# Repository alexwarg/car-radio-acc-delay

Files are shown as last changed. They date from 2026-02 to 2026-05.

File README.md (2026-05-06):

# Car Head-Unit ACC Timer

A small circuit and firmware based on an ATtiny85 that adds independent power-button control to a car head unit.

The device sits in-line with the vehicle's ACC (accessory/ignition) signal and gives you two extra capabilities:

- **ACC on:** the button can toggle the head unit off or back on while the ignition remains on.
- **ACC off:** the button turns the head unit on with an automatic 30-minute power-off timer, so you can keep listening after parking without draining the battery.

Power consumption in the off state is around 40 µA.

The project is available under the MIT license (see `LICENSE.txt`).

## Hardware

Minimal component count around an ATtiny85, designed for very low quiescent current.

The KiCad schematic and PCB layout are in `hardware/auto-acc-timer/`. A 3D-printable housing is in `hardware/auto-acc-timer/housing/`.

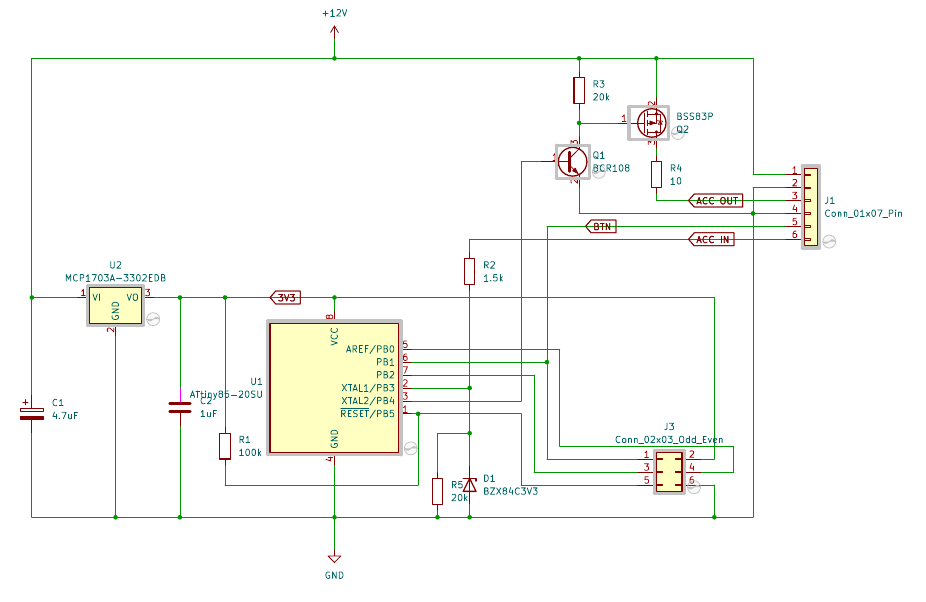
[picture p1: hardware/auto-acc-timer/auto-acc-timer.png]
Schematic


### MCU Pin Assignment

| Pin | Direction | Signal |
|-----|---|---|
| PB1 | Input | Power button (active low, internal pull-up) |
| PB3 | Input | ACC input from vehicle |
| PB4 | Output | ACC output to head unit |
| PB0 | I²C SDA | Optional OLED display |
| PB2 | I²C SCL | Optional OLED display |

### J1 — Main Connector (1×6, 2.54 mm)

| Pin | Signal | Description |
|-----|---|---|
| 1 | +12V | Vehicle power input |
| 2 | GND | Ground |
| 3 | ACC OUT | Switched ACC output to head unit |
| 4 | GND | Ground |
| 5 | BTN | Power button input |
| 6 | ACC IN | ACC input from vehicle ignition |

### J3 — ISP Programming Header / OLED Display (2×3, 2.54 mm)

| Pin | Signal | Description |
|-----|---|---|
| 1 | MOSI (PB1) | SPI data in — shared with BTN net |
| 2 | VCC (3V3) | 3.3 V supply |
| 3 | SCK (PB2) | SPI clock / I²C SCL |
| 4 | MISO (PB0) | SPI data out / I²C SDA |
| 5 | RESET | MCU reset |
| 6 | GND | Ground |

J3 doubles as the OLED display connector. Connect an SSD1306 128×32 display using pins 2 (VCC), 3 (SCL), 4 (SDA), and 6 (GND).

## Operating Modes

| Condition | Short press | Long press |
|---|---|---|
| ACC on, output on | Turn output off | — |
| ACC on, output off | Turn output on | — |
| ACC off, output off | Turn output on (starts 30 min timer) | — |
| ACC off, timer running | Cancel timer, turn output off | Reset timer to 30 min |

When the timer expires the output is cut automatically.

## Optional OLED Display

Compile with `USE_I2C=1` to enable an SSD1306 OLED (128×32) that shows the remaining time in `MM:SS` using a 7-segment font. A settings menu (long-press when idle) lets you adjust the power-off timer and the ACC-off delay; values are stored in EEPROM.

## Building

Requires `avr-g++` (C++20) and `avrdude`. The programmer is a Bus Pirate on `/dev/ttyUSB0`.

```sh
# Build firmware
make

# Flash firmware and EEPROM
make upload

# Regenerate font headers (requires tools/ttf2bmh.py)
make fonts
```

The build output lands in `.build/src/firmware.hex`.

## Software Overview

| File | Purpose |
|---|---|
| `src/main.cc` | Application logic, pin setup, task loop |
| `src/timer.h` | 40-bit timer on USI/Timer1, ~1 kHz resolution at 8 MHz |
| `src/debounce.h` / `btn.h` | Debounce and button event detection (short/long/double press) |
| `src/task_list.h` | Cooperative task scheduler with idle-mode sleep |
| `src/i2c.h` | Non-blocking bit-bang I²C master driven by a flash-resident command program |
| `src/display.h` / `display.cc` | SSD1306 driver and font renderer |

See [`doc/i2c.md`](doc/i2c.md) for a detailed description of the I²C implementation.

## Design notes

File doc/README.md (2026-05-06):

This is firmware for an AVR microcontroller (likely ATtiny85 or similar) that implements an ACC (accessory power) delay timer for 
a car radio. Here's what the code does:

## Core Purpose

It sits between a car's ACC ignition signal and the car radio, giving you manual control over when the radio turns off — useful
for listening to the radio after parking without draining the battery.

## How It Works

### Inputs:

 - ACC_IN (pin 3): The car's ignition/ACC signal
 - PWR_BTN (pin 1): A manual power button

### Output:

 - ACC_OUT (pin 4): The signal sent to the radio

### Operating Modes (Timed_pwr_on)

1. ACC on (P_acc): When the ignition is on, the radio output mirrors it. The button can toggle the radio off/on while ignition
remains on.
2. Timer mode (P_timer): When the ignition turns off, you can press the button to keep the radio on for a 30-minute countdown. A
long press resets the timer back to 30 minutes. When the timer expires, it cuts power automatically
3. Off (P_off): Radio output is off.

## Supporting Components

 - timer.h: A 40-bit hardware timer built on AVR Timer1 with an 8192 prescaler, providing ~1kHz resolution at 8MHz. Used for
   debouncing and timeout tracking.
 - debounce.h / btn.h: Debounce logic for the ACC input and button, distinguishing short press, long press, and double-click.
 - task_list.h: A cooperative task loop that puts the MCU to sleep (idle mode) between events to save power, waking on pin-change  
   interrupts.
 - display.h / i2c.h: Optional SSD1306 OLED display support (compiled with USE_I2C=1) to show remaining time in MM:SS format using 
   a 7-segment font, plus a settings menu for configuring the timers — stored in EEPROM.
 - display.cc: Font rendering logic for blitting characters to the OLED over I2C.

## Summary

Short press while ACC is off → turn radio on with 30-min timer. Long press while timer is ticking → reset timer to 30 min. Timer
expires → radio off. With the display enabled, you also get a settings UI to configure the timeout duration via EEPROM.

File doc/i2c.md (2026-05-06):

# I2C Implementation

The I2C implementation is a **software bit-bang master** using the AVR's USI (Universal Serial Interface) peripheral as a shift register.

## Physical Layer

The USI hardware on the ATtiny handles the actual bit shifting. `USICR` configures it in two-wire mode with external clock, and `USIDR` holds the data register. The `_usitc()` call toggles SCL via the USI control register, which also clocks the shift register. SDA is manipulated directly as a GPIO.

Start and stop conditions are generated manually by controlling SDA/SCL timing: start = SDA goes low while SCL is high; stop = SDA goes high while SCL is high.

## Command Queue

Rather than a blocking loop, the driver is **non-blocking and cooperative**. All I2C operations are described as a compile-time byte sequence of commands stored in flash (program memory via `Pgm`). The command opcodes are:

| Opcode | Meaning |
|---|---|
| `C_start` | Generate I2C start condition |
| `C_stop` | Generate I2C stop condition |
| `C_send_bytes_inline` | Send N bytes embedded in the command stream |
| `C_send_bytes` | Send N bytes from a pointer |
| `C_send_bytes_rep` | Repeat a single byte N times (for clearing display RAM) |
| `C_send_bytes_rep_len` | Same but length comes from a RAM struct at runtime |
| `C_send_bytes_ram_len` | Send N bytes from a RAM pointer (for dynamic data) |
| `C_callback` | Call a function mid-sequence without stopping |
| `C_end` | End of sequence, call finalizer |

`_next_cmd()` walks this byte stream, dispatching each opcode. The `resume` function pointer holds where to continue next time `step()` is called from the main task loop.

## Byte Transmission

`_send_byte<get_dr>()` loads `USIDR` with the next byte, then `_send_bits_loop()` clocks it out 8 times using `_usitc()`. After 8 bits (`USISR & USIOIF`), it switches SDA to input to receive the ACK/NACK from the device. If NACK, it aborts and calls `_stop()`; if ACK and more bytes remain, it recurses; otherwise advances to `_next_cmd()`.

## Do-While Loop Construct

`do_while_end<condition, finish>(code)` is a compile-time helper that builds a command sequence with a tail callback that re-jumps to the start of the sequence if `condition()` returns true. This is how `Display::time()` iterates over 5 digit positions — the loop state is kept in `Disp_time::state` in RAM, and the condition lambda increments `state.pos` each pass.

## Command Construction with `mk_cmds`

`mk_cmds(...)` uses variadic templates and `Packed_tuple` to concatenate heterogeneous command structs into a single tightly-packed byte array at compile time, which then gets placed in flash via `Pgm(...)`. The result is zero runtime overhead for building the command sequences — they're fully laid out at compile time.

## Summary

A non-blocking I2C master where the entire operation (init OLED, clear, draw digits, loop) is described as a flash-resident command program, executed one step per main-loop tick, with a function pointer as the "program counter". Very tight for an 8-bit MCU with 512 bytes of RAM.

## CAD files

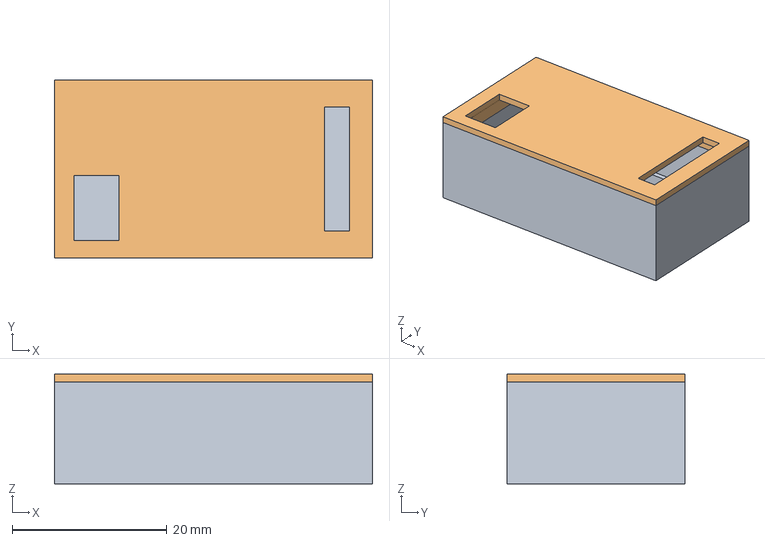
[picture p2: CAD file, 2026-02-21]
hardware/auto-acc-timer/housing/housing.FCStd
41.1 x 23.0 x 14.2 mm

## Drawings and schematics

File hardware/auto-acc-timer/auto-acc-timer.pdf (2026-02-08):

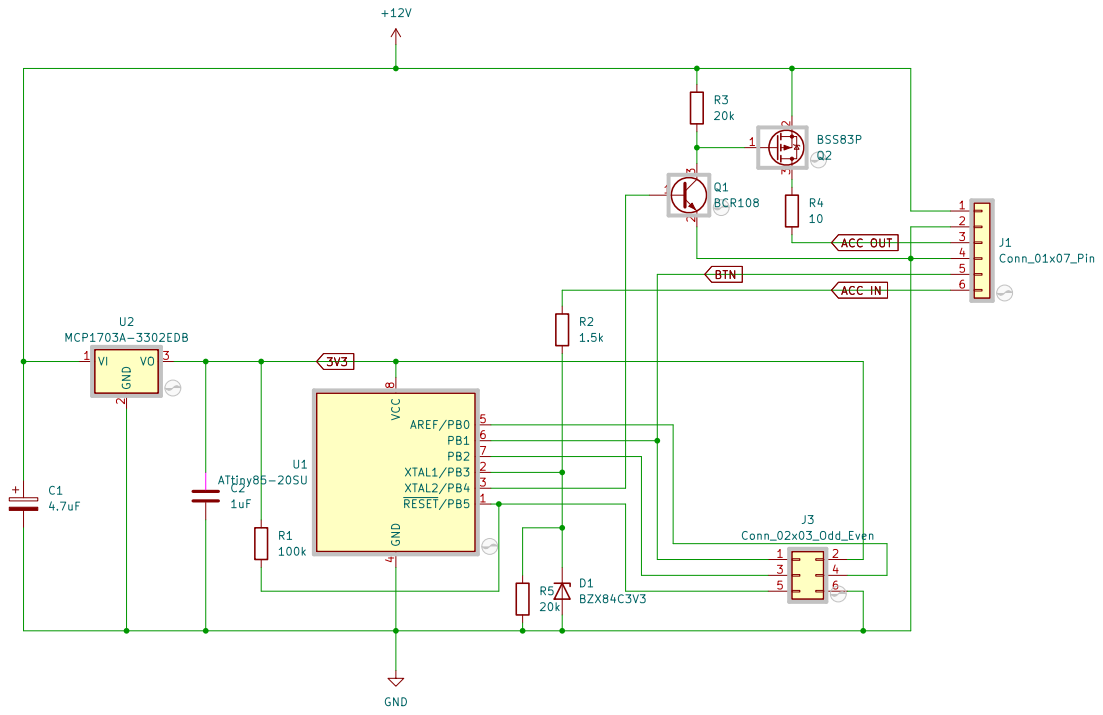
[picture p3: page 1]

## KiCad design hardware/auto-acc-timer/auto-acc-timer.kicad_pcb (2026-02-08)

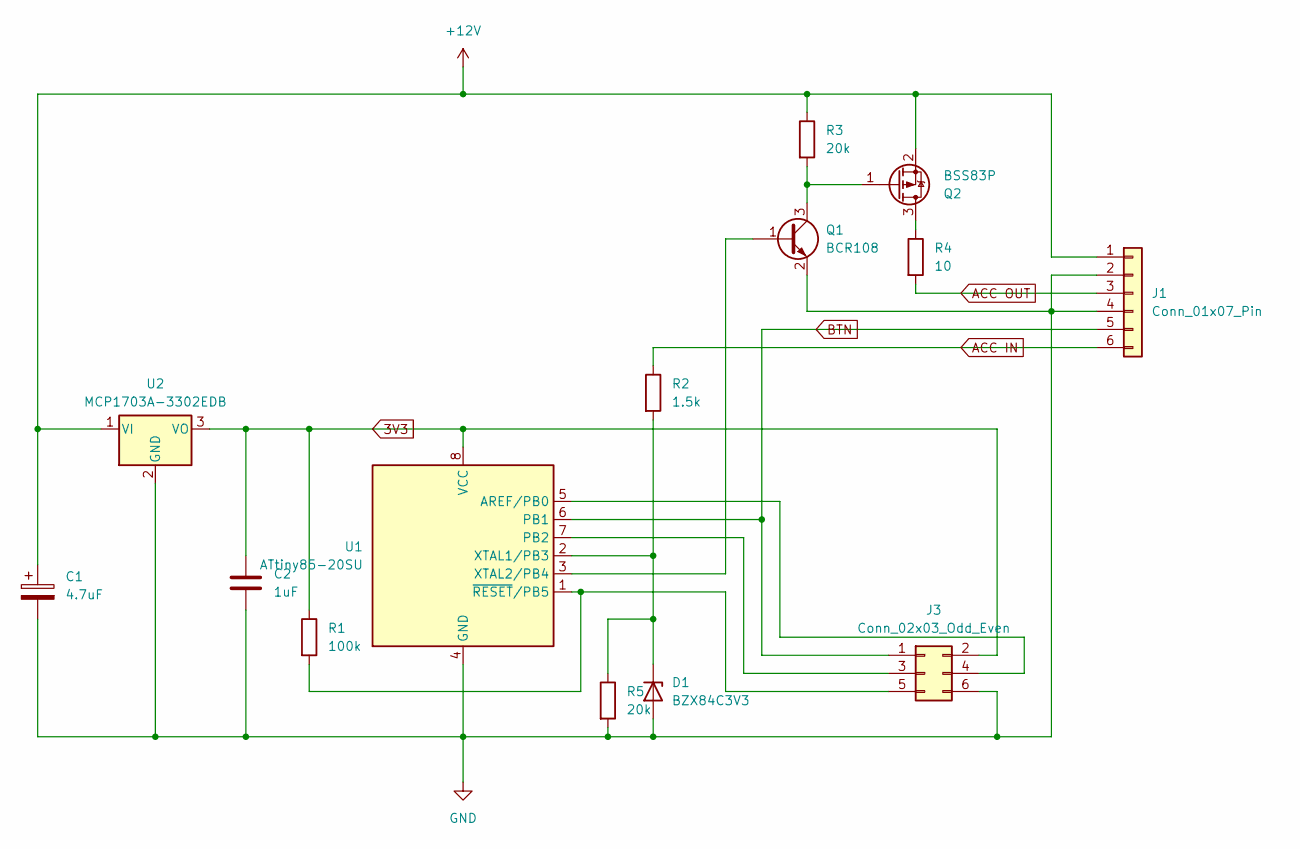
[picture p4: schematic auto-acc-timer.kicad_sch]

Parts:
C1: 4.7uF; CP_Elec_4x5.8
C2: 1uF; C_0805_2012Metric_Pad1.18x1.45mm_HandSolder
D1: BZX84C3V3; SOT-23
J1: Conn_01x07_Pin; PinHeader_1x06_P2.54mm_Vertical
J3: Conn_02x03_Odd_Even; PinHeader_2x03_P2.54mm_Vertical
Q1: BCR108; SOT-23
Q2: BSS83P; SOT-23
R1: 100k; R_0805_2012Metric_Pad1.20x1.40mm_HandSolder
R2: 1.5k; R_0805_2012Metric_Pad1.20x1.40mm_HandSolder
R3, R5: 20k; R_0805_2012Metric_Pad1.20x1.40mm_HandSolder
R4: 10; R_0805_2012Metric_Pad1.20x1.40mm_HandSolder
U1: ATtiny85-20SU; SOIC-8_5.3x5.3mm_P1.27mm
U2: MCP1703A-3302EDB; SOT-223-3_TabPin2

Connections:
3V3: C2.1, J3.2, R1.1, U1.8 (VCC), U2.3 (VO)
+12V: C1.1, J1.1, Q2.2 (S), R3.1, U2.1 (VI)
ACC IN: J1.6, R2.1
ACC OUT: J1.3, R4.2
BTN: J1.5, J3.1, U1.6 (PB1)
GND: C1.2, C2.2, D1.1 (A), J1.2, J1.4, J3.6, Q1.2 (E), R5.2, U1.4 (GND), U2.2 (GND)
unnamed: D1.3 (K), R2.2, R5.1, U1.2 (XTAL1/PB3)
unnamed: J3.3, U1.7 (PB2)
unnamed: J3.4, U1.5 (AREF/PB0)
unnamed: J3.5, R1.2, U1.1 (~RESET/PB5)
unnamed: Q1.1 (B), U1.3 (XTAL2/PB4)
unnamed: Q1.3 (C), Q2.1 (G), R3.2
unnamed: Q2.3 (D), R4.1

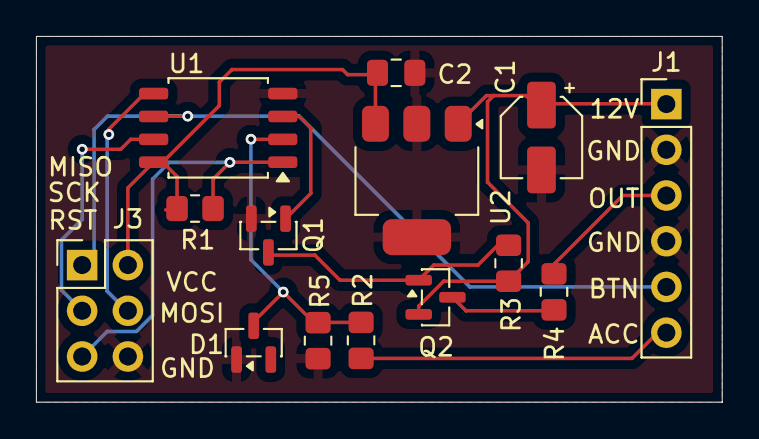
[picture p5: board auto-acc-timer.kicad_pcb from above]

Board: 2 copper layers, 38.1 x 20.3 mm, 14 parts (0 on the bottom side), 13 nets.

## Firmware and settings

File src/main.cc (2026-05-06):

// Licensed under the MIT License. See LICENSE.txt file in the project root.

/**
 * ACC timer
 *
 * The project is designed to take two inputs, an ingition (ACC) signal, and a power button.
 * The output is an ignition (ACC) signal with extra function:
 *  - In case the ACC input transitions from low-to-high the ACC output is switched to high.
 *    As long ass ACC input remains high, the button allows switch off and on of the ACC output.
 *  - In case of ACC input is low, the button allows to toggle the ACC output on and off, with
 *    an additional timer of 30 minutes to automatically switch off the ACC output.
 */

#include <cstddef>

#include <avr/io.h>
#include <avr/interrupt.h>
#include <avr/pgmspace.h>
#include <avr/eeprom.h>

#include "timer.h"
#include "irq_guard.h"
#include "debounce.h"
#include "btn.h"
#include "cxx_duration.h"
#include "task_list.h"
#include "sleep_support.h"

#include "i2c.h"
#include "display.h"


enum {
  ACC_OUT_PIN = 4,
  ACC_IN_PIN  = 3,
  PWR_BTN_PIN = 1,

  ACC_OUT_MSK = 1 << ACC_OUT_PIN,
  ACC_IN_MSK  = 1 << ACC_IN_PIN,
  PWR_BTN_MSK = 1 << PWR_BTN_PIN,
};

enum : unsigned long
{
  PWR_DOWN_DELAY_SEC = 30 * 60ul, // poer off timer for manually powerd on mode (without ACC on)
  ACC_DOWN_DELAY_SEC = 0, // delay power down after ACC off for n seconds
};

#define USE_I2C 0

template<typename T>
class Eem
{
  T _v;

public:
  Eem() = default;
  constexpr Eem(T const &v) noexcept : _v(v) {}
  Eem(Eem const &) = delete;
  Eem(Eem &&) = delete;
  Eem &operator = (Eem const &) = delete;
  Eem &operator = (Eem &&) = delete;


  T get() const noexcept { return T(eeprom_read_word(&_v._c)); }
  void write(T const &v) noexcept { eeprom_write_word(&_v._c, v.count()); }

  operator T () const noexcept { return get(); }


};

//---------------------------------------------------------
//  main application logic: handling the ACC output pin
//  accoring to input state and timer based power-off...
template<unsigned long ON_TIME_SECS>
struct Timed_pwr_on
{
  using Cnt_max_type = cxx::qseconds<~0ul>;
  static constexpr cxx::seconds On_time = ON_TIME_SECS;
  static constexpr cxx::milliseconds On_time_ms = On_time;
  static constexpr Cnt_max_type On_time_qs = cxx::duration_cast<Cnt_max_type>(On_time);
  using Cnt_type = cxx::qseconds<2 * On_time_qs.count()>;

  static constexpr cxx::seconds Acc_delay = ACC_DOWN_DELAY_SEC;
  static constexpr Cnt_max_type Acc_delay_qs = cxx::duration_cast<Cnt_max_type>(Acc_delay);

#if USE_I2C
  static Eem<Cnt_type> On_time_diff;
  static Eem<Cnt_type> Acc_delay_diff;
#else
  static constexpr Cnt_type On_time_diff = On_time_qs;
  static constexpr Cnt_type Acc_delay_diff = Acc_delay_qs;
#endif

  enum
  {
    P_off   = 0, //< ACC output is off
    P_acc   = 1, //< ACC output is on due to ACC input on
    P_timer = 2, //< ACC output is on and power-off timer is ticking

    P_settings = 4,
    P_edit_setting = 8,
    P_set_off_tmr = 0x00,
    P_set_acc_delay =0x10,
  };

  Cnt_type _pwr_off_time;
  uint8_t _pwr;

#if USE_I2C
  bool in_settings() const { return _pwr & P_settings; }
  bool in_settings_edit() const { return _pwr & P_edit_setting; }
#else
  bool in_settings() const { return false; }
  bool in_settings_edit() const { return false; }
#endif

  uint8_t current_setting() const
  {
    return _pwr & P_set_acc_delay;
  }

  uint8_t next_setting()
  {
    _pwr ^= P_set_acc_delay;
    return current_setting();
  }

  void enter_settings()
  {
    _pwr = (_pwr & 7) | P_settings;
  }

  void leave_settings()
  {
    _pwr = (_pwr & 3);
  }

  void enter_settings_edit()
  {
    _pwr |= P_edit_setting;
  }

  void leave_settings_edit()
  {
    _pwr &= ~P_edit_setting;
  }

  bool is_on() const
  {
    return _pwr & (P_acc | P_timer);
  }

  bool is_ticking() const
  {
    return _pwr & P_timer;
  }

  Cnt_type eta(Cnt_type now) const
  { return _pwr_off_time - now; }


  bool timeout(Cnt_type now) const
  {
    if (!(_pwr & P_timer))
      return false;

    using Scnt = cxx::signed_type_t<Cnt_type>;

    if (static_cast<Scnt>(now - _pwr_off_time) >= Scnt::zero())
      return true;

    return false;
  }

  void hit()
  {
    _pwr &= ~P_timer;
    switch_acc_off();
  }

  void start_timer(Cnt_type timer)
  {
    _pwr_off_time = timer;
    _pwr |= P_timer;
  }

  bool stop_timer()
  {
    if (!(_pwr & P_timer))
      return false;

    _pwr &= ~P_timer;
    return true;
  }

  bool running() const { return _pwr & P_timer; }
  // timers always can sleep, just might not power down...
  bool might_sleep() const { return true; }
  // timers always can sleep, just might not power down...
  bool might_power_down() const { return !running(); }

  void switch_acc_on()
  {
    PORTB |= ACC_OUT_MSK;
  }

  void switch_acc_off()
  {
    PORTB &= ~ACC_OUT_MSK;
  }

  template<typename ACC>
  bool power_btn(ACC const &acc, Cnt_type now)
  {
    if (_pwr & P_timer)
      {
        stop_timer();
        switch_acc_off();
        return true;
      }

    if (_pwr & P_acc)
      {
        _pwr &= ~P_acc;
        switch_acc_off();
        return true;
      }

    // off
    if (acc.state())
      _pwr |= P_acc;
    else
      start_timer(now + On_time_diff);

    switch_acc_on();
    return false;
  }

  void long_btn_press(Cnt_type now)
  {
    if (is_ticking())
      start_timer(now + On_time_diff);
  }

  template<typename ACC>
  void acc_update(ACC const &acc, Cnt_type now)
  {
    if (acc.state())
      {
        if (_pwr & P_timer)
          _pwr = (_pwr & ~P_timer) | P_acc;
        else if (!(_pwr & P_acc))
          {
            _pwr |= P_acc;
            switch_acc_on();
          }

        return;
      }

    // acc input is off ...
    if (_pwr & P_acc)
      {
        _pwr &= ~P_acc;
        if (!in_settings() && (Cnt_type)Acc_delay_diff)
          start_timer(now + Acc_delay_diff);
        else
          switch_acc_off();
      }
  }

  // task loop API
  using update_time_type = Cnt_type;
  using wakeup_time_type = Cnt_type;

  static void init(auto &&...) {}

  void update(auto const &now, auto &&...)
  {
    // if we hit the timeout, handle it
    if (timeout(cxx::duration_cast<Cnt_type>(now)))
      hit();
  }

  bool wakeup_pending(auto const &now) const
  {
    return timeout(now);
  }

  static void clear_wakeups() {}
};

#if USE_I2C
template<unsigned long ON_TIME_SECS>
EEMEM Eem<typename Timed_pwr_on<ON_TIME_SECS>::Cnt_type> Timed_pwr_on<ON_TIME_SECS>::On_time_diff(On_time_qs);

template<unsigned long ON_TIME_SECS>
EEMEM Eem<typename Timed_pwr_on<ON_TIME_SECS>::Cnt_type> Timed_pwr_on<ON_TIME_SECS>::Acc_delay_diff(Acc_delay_qs);
#endif

//---------------------------------------------------------
// Timer / Clock instance
static cxx::Timer timer;

static void init_clk()
{
  CLKPR = 0x80;
  CLKPR = 0x00; // prescaler: 0 -> 8MHz
}

static void init_timer1()
{
  TCCR1 = 0x0e; // normal mode + 8192 prescaler
  TIFR  = 0xff;
  TIMSK = 0x04; // OVFL 1
  GTCCR = 0;
}

//ISR(TIMER0_COMPA_vect)
//ISR(TIMER0_OVF_vect)
ISR(TIMER1_OVF_vect)
{
  asm volatile ("" : "=m"(timer._cnt));
  ++timer._cnt;
  asm volatile ("" : : "m"(timer._cnt));
}

//---------------------------------------------------------
// recording pin changed IRQ and translating it into a
// wakeup reason for the task loop
class Pin_changed_task
{
  uint8_t _s;

public:
  using update_time_type = void;
  using wakeup_time_type = void;

  void set() { _s = true; }
  void clear() { _s = false; }
  bool is_set() const { return _s; }

  bool wakeup_pending(auto ...) const
  {
    return is_set();
  }

  void clear_wakeups()
  { clear(); }

  void update(auto &&...) const {}
  void init(auto &&...) const {}

  bool might_sleep() const { return true; }
  bool might_power_down() const { return true; }
};

static Pin_changed_task _pin_changed;
ISR(PCINT0_vect)
{
  _pin_changed.set();
}
//---------------------------------------------------------


//---------------------------------------------------------
// mixin for wrapping a debounced IO pin to be handled in a
// task loop.
// The DERVIVED class needs to provide on_update() function
// for handling updates.
template<typename DERIVED, auto &pin>
struct Io_pin_task
{
  using wakeup_time_type = void;

  void update(auto &&now, uint8_t pv)
  {
    if (!pin.update(now, pv))
      return;

    static_cast<DERIVED *>(this)->on_update(now, pin.pressed(now));
  }

  template<typename ...Args>
  void init(Args &&...args) { pin.init(std::forward<Args>(args)...); }

  bool might_sleep() const { return pin.might_sleep(); }
  bool might_power_down() const { return pin.might_power_down(); }

  void clear_wakeups() const {}
  bool wakeup_pending(auto ...) const { return false; }
};
//---------------------------------------------------------


// 30minutes timeout
using Tmr = Timed_pwr_on<PWR_DOWN_DELAY_SEC>;

static Tmr timed_pwr;
static cxx::Debounce<ACC_IN_MSK, cxx::Timer::Hires_type<16>(10)> acc_in;
static cxx::Btn<PWR_BTN_MSK, cxx::Timer::Hires_type<16>(10), true> pwr_btn;

//---------------------------------------------------------
// ACC input pin handling
class Acc_in : public Io_pin_task<Acc_in, acc_in>
{
public:
  using update_time_type = cxx::Timer::Time_type; //< needed for task loop
  void on_update(update_time_type const &now, int8_t key)
  {
    if (key != 0)
      timed_pwr.acc_update(acc_in, cxx::duration_cast<Tmr::Cnt_type>(now));
  }
};


//---------------------------------------------------------
#if USE_I2C

#include "img_settings.h"
#include "img_off.h"
#include "img_delay.h"
#include "img_s.h"

I2c_master I2c_master::m;
Display Display::d;


//---------------------------------------------------------
// task around i2c and display
struct Display_task
{
  using update_time_type = Tmr::Cnt_type;
  using wakeup_time_type = void;

  static I2c_master::Start_ptr i2c_queue;

  static void i2c_start_cmds(I2c_master::Start_ptr p)
  {
    might_init();
    if (I2c_master::m.busy())
      i2c_queue = p;
    else
      I2c_master::m.start_cmds(p);
  }

  static void i2c_finish_cmds(uint8_t err, Pgm_ptr<uint8_t const>)
  {
    if (err)
      {
        Display::d._initialized = false;
        Display::d._on = false;
        i2c_queue = nullptr;
        return;
      }

    if (!i2c_queue)
      return;

    auto tmp = i2c_queue;
    i2c_queue = nullptr;
    I2c_master::m.start_cmds(tmp);
  }

  static void might_init()
  {
    if (!Display::d._initialized)
      Display::d.init<[](uint8_t e, Pgm_ptr<uint8_t const> p)
      {
        if (!e)
          {
            Display::d._initialized = true;
            Display::d._on = 0;
            i2c_finish_cmds(e, p);
          }
      }>();
  }

  static void init(auto &&...)
  {
    I2c_master::m.init();
    might_init();
  }

  static void show_time(cxx::seconds16 const &eta, bool force)
  {
    Display::d.time<i2c_finish_cmds>(eta.count(), force, i2c_start_cmds);
  }

  static void update(auto const &now, auto &&)
  {
    I2c_master::m.step();

    if (timed_pwr.is_ticking() && !I2c_master::m.busy())
      {
        Display::d._on = 1;
        // assume eta is (far) less than 4h == 240 * 60 seconds (16bit is big enough)
        show_time(cxx::duration_cast<cxx::seconds16>(timed_pwr.eta(cxx::duration_cast<Tmr::Cnt_type>(now))), false);
      }
    else if(!(timed_pwr.is_ticking() || timed_pwr.in_settings()) && Display::d._on)
      {
        Display::d._on = 0;
        Display::d.off<i2c_finish_cmds>(i2c_start_cmds);
      }
  }

  static bool
  might_sleep() { return I2c_master::m.might_sleep(); }

  static bool
  might_power_down() { return I2c_master::m.might_power_down(); }

  static constexpr bool
  wakeup_pending(auto ...) { return false; }

  static void clear_wakeups() {}

  using Etime = decltype(timed_pwr)::Cnt_type;
  static Etime _edit_time;

  static void enter_settings()
  {
    timed_pwr.enter_settings();
    Display::d._on = 1;
    static auto const c = Pgm(I2c_master::mk_cmds(
          Display::mk_blit<img_settings>(4, 0, 0xaf),
          Display::mk_blit<img_off>(4, 2),
          I2c_master::End(i2c_finish_cmds)));

    i2c_start_cmds(&c);
    _edit_time = timed_pwr.On_time_diff;
    show_time(cxx::duration_cast<cxx::seconds16>(_edit_time), true);
  }

  static void leave_settings()
  {
    static auto const c = Pgm(I2c_master::mk_cmds(
          Display::mk_clr(4, 0, 32, 4),
          I2c_master::End(i2c_finish_cmds)));

    i2c_start_cmds(&c);
    timed_pwr.leave_settings();
  }

  static void enter_settings_edit()
  {
    timed_pwr.enter_settings_edit();
    static auto const c = Pgm(I2c_master::mk_cmds(
          Display::mk_blit<img_s>(4 + img_settings::w + 2, 0),
          I2c_master::End(i2c_finish_cmds)));

    i2c_start_cmds(&c);
  }

  static void leave_settings_edit()
  {
    switch (timed_pwr.current_setting())
      {
      case 0x10:
        timed_pwr.Acc_delay_diff.write(_edit_time);
        break;
      case 0x00:
        timed_pwr.On_time_diff.write(_edit_time);
        break;
      }
    timed_pwr.leave_settings_edit();
    static auto const c = Pgm(I2c_master::mk_cmds(
          Display::mk_clr(4 + img_settings::w + 2, 0, img_s::w, img_s::h / 8, 0),
          I2c_master::End(i2c_finish_cmds)));

    i2c_start_cmds(&c);
  }

  static void setings_delay()
  {
    static auto const c = Pgm(I2c_master::mk_cmds(
          Display::mk_blit<img_delay>(4, 2),
          I2c_master::End(i2c_finish_cmds)));

    i2c_start_cmds(&c);
    _edit_time = timed_pwr.Acc_delay_diff;
    show_time(cxx::duration_cast<cxx::seconds16>(_edit_time), true);
  }

  static void settings_pwr_off()
  {
    static auto const c = Pgm(I2c_master::mk_cmds(
          Display::mk_blit<img_off>(4, 2),
          Display::mk_clr(4 + img_off::w, 2, img_delay::w - img_off::w, img_off::h / 8, 0),
          I2c_master::End(i2c_finish_cmds)));

    i2c_start_cmds(&c);
    _edit_time = timed_pwr.On_time_diff;
    show_time(cxx::duration_cast<cxx::seconds16>(_edit_time), true);

  }

  static void handle_settings(cxx::Timer::Time_type const &, int8_t key)
  {
    switch (key)
      {
      case 0:
      default:
        break;
      case 1: // short press / click
        if (!timed_pwr.in_settings_edit())
          {
            switch (timed_pwr.next_setting())
              {
              case 0x10:
                setings_delay();
                break;

              case 0x00:
                settings_pwr_off();
                break;
              }
          }
        else
          {
            switch (timed_pwr.current_setting())
              {
              case 0x10:
                _edit_time = _edit_time + cxx::seconds16(5);
                if (_edit_time > Etime(cxx::seconds8(30)))
                  _edit_time = cxx::seconds(0);
                show_time(cxx::duration_cast<cxx::seconds16>(_edit_time), true);
                break;

              case 0x00:
                _edit_time = _edit_time + cxx::minutes8(10);
                if (_edit_time > Etime(cxx::minutes8(60)))
                  _edit_time = cxx::seconds(0);
                show_time(cxx::duration_cast<cxx::seconds16>(_edit_time), true);
                break;
              }
          }
        //timed_pwr.power_btn(acc_in, cxx::duration_cast<Tmr::Cnt_type>(now));
        break;
      case 2: // long press / click
        leave_settings();
        break;
      case 3: // double click
        if (!timed_pwr.in_settings_edit())
          enter_settings_edit();
        else
          leave_settings_edit();
      }
  }
};

decltype(timed_pwr)::Cnt_type Display_task::_edit_time;
I2c_master::Start_ptr Display_task::i2c_queue;
#endif

//---------------------------------------------------------
// power button handling
class Pwr_btn : public Io_pin_task<Pwr_btn, pwr_btn>
{
public:
  using update_time_type = cxx::Timer::Time_type; //< needed for task loop
  void on_update(update_time_type const &now, int8_t key)
  {
#if USE_I2C
    if (timed_pwr.in_settings())
      {
        Display_task::handle_settings(now, key);
        return;
      }
#endif

    switch (key)
      {
      case 0:
      default:
        break;
      case 1: // short press / click
        timed_pwr.power_btn(acc_in, cxx::duration_cast<Tmr::Cnt_type>(now));
        break;
      case 2: // long press / click
        if (timed_pwr.is_ticking())
          timed_pwr.long_btn_press(cxx::duration_cast<Tmr::Cnt_type>(now));
#if USE_I2C
        else
          Display_task::enter_settings();
#endif
        break;
      }
  }

};


//---------------------------------------------------------
#if USE_I2C

using Tasks = Task_list<Acc_in, Pwr_btn, Tmr &, Pin_changed_task &, Display_task>;

#else // USE_I2C == 0 ... no display support

using Tasks = Task_list<Acc_in, Pwr_btn, Tmr &, Pin_changed_task &>;

#endif // USE_I2C == 0

//---------------------------------------------------------
int main()
{
  Tasks tasks { Acc_in{}, Pwr_btn{}, timed_pwr, _pin_changed };

  init_clk();
  init_timer1();

  set_sleep_mode(SLEEP_MODE_IDLE | _SLEEP_ENABLE_MASK);

  DDRB  |= ACC_OUT_MSK; // ACC_OUT as output
  PORTB |= PWR_BTN_MSK; // pullup power btn pin

  // after configuring the IOs initilize the debouncers
  tasks.init(uint8_t(PINB));

  sei();

  GIMSK = 1 << 5;
  PCMSK = ACC_IN_MSK | PWR_BTN_MSK;

  tasks.task_loop(timer, Sleep_support{}, &PINB);
}

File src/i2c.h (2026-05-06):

// Licensed under the MIT License. See LICENSE.txt file in the project root.

#pragma once

#include <avr/io.h>

#include <stddef.h>
#include <avr/pgmspace.h>

#include "cxx_pgm.h"

#ifndef SDA_BIT
#if defined(__AVR_ATtiny25__) || defined(__AVR_ATtiny45__) || defined(__AVR_ATtiny85__)
enum {
    SDA_BIT = 0,
    SCL_BIT = 2,
};
#define SDA_BIT SDA_BIT
#define SCL_BIT SCL_BIT
#define SDA_PIN PINB
#define SCL_PIN PINB
#define SDA_PORT PORTB
#define SCL_PORT PORTB
#define SDA_DDR DDRB
#define SCL_DDR DDRB
#endif
#endif

struct I2c_master
{
  enum Cmd : uint8_t
  {
    C_end = 0,
    C_callback,
    C_start,
    C_stop,
    C_send_bytes,
    C_send_bytes_inline,
    C_send_bytes_rep,
    C_send_bytes_rep_len,
    C_send_bytes_ram_len,
  };

  enum : uint8_t
  {
    M_SCL = 1 << SCL_BIT,
    M_SDA = 1 << SDA_BIT,
  };

  typedef void (*Finalizer)(uint8_t err, Pgm_ptr<uint8_t const>);
  using Start_ptr = Pgm_ptr<void const>;

  struct Send_buffer_data
  {
    Gen_ptr<void const> addr;
    uint8_t len;
  } __attribute__((packed));

  struct Send_bytes_data
  {
    uint8_t len;
    Gen_ptr<void const> addr;
    Send_bytes_data() = default;
    constexpr Send_bytes_data(uint8_t len, Gen_ptr<void const> addr) noexcept
    : len(len), addr(addr) {}
  } __attribute__((packed));

  struct Repeat_byte_data
  {
    uint8_t len;
    uint8_t byte;
  } __attribute__((packed));

  static I2c_master m;

private:
  //uint8_t _state;
  typedef void (*resume_fn)();
  resume_fn resume;

  using Cmd_ptr = Pgm_ptr<uint8_t const>;

  Cmd_ptr cmd;

  uint8_t len;
  union {
    Gen_ptr<uint8_t const> buf;
    uint8_t buf_byte;
  };

  static uint8_t _scl() __attribute__((always_inline))  { return SCL_PIN & M_SCL; }
  static void _scl_l() __attribute__((always_inline))  { SCL_PORT &= ~M_SCL; }
  static void _scl_h() __attribute__((always_inline))  { SCL_PORT |= M_SCL; }

  static void _sda_l() __attribute__((always_inline))  { SDA_PORT &= ~M_SDA; }
  static void _sda_h() __attribute__((always_inline))  { SDA_PORT |= M_SDA; }

  static void _sda_in() __attribute__((always_inline))  { SDA_DDR &= ~M_SDA; }
  static void _sda_out() __attribute__((always_inline))  { SDA_DDR |= M_SDA; }

  void _resume_err(uint8_t err = 1) noexcept
  {
    len = err;
    resume = _next_cmd;
  }

  void _resume_next() noexcept
  {
    resume = _next_cmd;
  }

  void _stop()
  {
    if (_scl())
      {
        USIDR = 0xff;
        _sda_in(); _sda_l(); // results in SDA = released high Z
        return _resume_next();
      }

    _sda_l(); _sda_out();
    _scl_h();
    resume = []() {
      if (!m._wait_scl())
        {
          USIDR = 0xff;
          _sda_in(); _sda_l(); // results in SDA = released high Z
          return m._resume_err(8);
        }

      m.resume = []() {
        USIDR = 0xff;
        m._sda_in(); // -> SDA released: high Z
        //PORTB &= ~ACC_OUT_MSK;
        return m._resume_next();
      };
    };
  }

  void _start()
  {
    // generate start condition
    _sda_in(); _sda_l(); // results in SDA = released high Z
    _scl_h();

    resume = []() {
      if (!m._scl())
        {
          if (++m.len >= 200)
            return m._resume_next();
          return;
        }

      m.len = 0;
      m._sda_out(); // LOW
      //m.resume = []() {
        m.resume = []() {
          m._scl_l();
          m._sda_h();
          //PORTB |= ACC_OUT_MSK;
          _next_cmd();
        };
      //};
    };
  }

  static void _usitc() __attribute__((always_inline))
  { USICR |= (1 << USITC); }

  static uint8_t _wait_scl() noexcept
  {
    uint8_t r;
    for (uint8_t x = 0; !(r = _scl()) && (x < 20); ++x)
      ;

    return r;
  }


  template<bool STRETCH, resume_fn fn>
  static void _send_bits_loop()
  {
    if (!_wait_scl())
      {
        if (STRETCH)
          return;
        else
          return m._resume_err();
      }

    for (;;)
      {
        m._usitc();
        if (USISR & (1 << USIOIF))
          break;

        m._usitc();
        if (!_wait_scl())
          return m._resume_err();
      }

    fn();
  }

  template<uint8_t (get_dr)()>
  static void _send_byte()
  {
    USISR = 0b11110000;
    USIDR = get_dr();
    m._usitc();
    m.resume = _send_bits_loop<false, [](){
      USISR = 0b11111110;
      m._sda_in();
      m._usitc();
      /*m.resume = */
      _send_bits_loop<true, []() {
        uint8_t nack = USIDR;
        m._sda_out();
        if (nack & 1)
          m._stop();
        else if (--m.len)
          _send_byte<get_dr>();
        else
          _next_cmd();
      }>();
    }>;
  }

  template<uint8_t (F)()> inline
  static void _send_bytes_x(Gen_ptr<void const> ptr, uint8_t len)
  {
    m.buf = gen_ptr_cast<uint8_t const>(ptr);
    m.len = len;
    _send_byte<F>();
  }

  static void _next_cmd()
  {
    static auto next_buf_byte = []() { return *(m.buf++); };

    //while (auto cmd = *m.cmd++) switch (cmd)
    switch (auto c = *m.cmd++)
      {
      case C_end:
      case C_callback:
        m.resume = (c == C_end) ? nullptr : _next_cmd;
          {
            Finalizer h = gen_ptr_recast<Finalizer const>(m.cmd)[0];
            auto current_cmd = m.cmd;
            m.cmd =  (c == C_end) ? nullptr : (m.cmd + sizeof(void*));
            //if (h)
              h(m.len, current_cmd - 1);
          }
        return;

      case C_start:
        if (!m.len)
          m._start();
        return;

      case C_stop:
        //if (!m.len)
          m._stop();
        return;

      case C_send_bytes:
        m.cmd += sizeof(Send_bytes_data);
        if (!m.len)
          {
            auto d = gen_ptr_recast<Send_bytes_data const>(m.cmd)[-1];
            m._send_bytes_x<next_buf_byte>(d.addr, d.len);
          }
        return;

      case C_send_bytes_inline:
          {
            uint8_t l = *m.cmd;
            m.cmd += l + 1;
            if (m.len)
              return;

            m._send_bytes_x<next_buf_byte>(m.cmd - l, l);
          }

        return;

      case C_send_bytes_rep:
        m.cmd += 2;
        if (!m.len)
          {
            m.len = m.cmd[-2];
            m.buf_byte = m.cmd[-1];
            m._send_byte<[]() { return m.buf_byte; }>();
          }
        return;

      case C_send_bytes_rep_len:
        m.cmd += sizeof(Repeat_byte_data const *);
        if (!m.len)
          {
            auto s = gen_ptr_recast<Repeat_byte_data const *>(m.cmd)[-1];
            if (!s->len)
              {
                m.resume = _next_cmd;
                return;
              }

            m.buf_byte = s->byte;
            m.len = s->len;
            m._send_byte<[]() { return m.buf_byte; }>();
          }
        return;

      case C_send_bytes_ram_len:
        m.cmd += sizeof(Send_buffer_data const *);
        if (!m.len)
          {
            auto s = gen_ptr_recast<Send_buffer_data const *>(m.cmd)[-1];
            m._send_bytes_x<next_buf_byte>(s->addr, s->len);
          }

        return;
    }
  }
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

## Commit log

2026-01-06 Initial version of CAR AUDIO DELAY
    This contains sime software for an AtTiny85 MCU and
    the hardware design.
    [auto-acc-timer.kicad_pcb, auto-acc-timer.kicad_sch]
2026-02-08 Fix wrong connection of Q2, move to KiCAD v 9
    The Q2 FET was connected the wrong way, fix that. and Move to KiCAD
    version9
    [auto-acc-timer.kicad_pcb, auto-acc-timer.kicad_sch]
2026-02-08 Adapt IO pins to schematic
2026-02-08 Rev 2 Hardware
    Add capacitor 1uF at 3.3V rail
    Add resistor to pull RESET high
    [auto-acc-timer.kicad_pcb, auto-acc-timer.kicad_sch]
2026-02-08 Make sure to initialize debaounce after IOs
    Add init methd to Debounce class and use it after setting up
    the IOs. So we start with the correct initial state and do
    not detect a button release from before enabling the pullup.
    [main.cc]
2026-02-08 Set timeout for auto-power-off to 30min
    The desired timer in real world is 30min so set this value.
2026-02-08 Actually enter sleep modes
    Call do_sleep() to actually enter the low-power modes of the MCU
2026-02-08 replace volatile globals by proper memory abbiers
    This shall allow for better optimization later
    [main.cc]
2026-02-08 Do not use arduino framework
    The code is absed on AVR libc only
2026-02-08 Optimize PCB layout
    [auto-acc-timer.kicad_pcb]
2026-02-08 Add schematic PDF
2026-02-08 Add README.md and schematic png
2026-02-21 Add housing CAD file
    [housing.FCStd]
2026-02-21 Better code for timer etc
2026-02-21 Add support for delayed ACC off
    delay the ACC output power off for 20 seconds after ACC input is going
    off.
2026-02-21 Add small notches in the housing
    The notches keep the PCB in place.
    [housing.FCStd]
2026-02-21 Make default duration unsigned
    This resembles better what we actually do with durations an generates
    better asm code. This also makes sure we do the right kind of compare
    for gracefully dealing with wraparound timer counters and time points
    and durations that go across wraparounds.
    Fixes a bug in case of long timeouts where "now + timeout" triggers a
    wrap around. In this case the maximum timeout is half of the counter
    maximum.
    [main.cc]
2026-02-21 Add old-school Makefile for building
    Allow to use GNU Make for compiling the code. This allows for more
    flexible use of tool-chains that are not bundled with PlatformIO.
2026-02-21 timer.h: abstract from TCNT0
    allow simple use of other timer counter for timers
2026-02-21 Use Timer1 for timekeeping
    switch from Timer0 to Timer1 for general time keeping. This frees Timer0
    for other tasks, such as USI.
2026-05-06 Add I2C support and some SD1306 support
    Asnyc I2C framework for the ATTiny25/45/85.
    Add SD1306 support...
2026-05-06 Add hooks in main.cc for i2c and display
2026-05-06 Run the CPU at 8MHz
    Adjust the prescaler for the CPU clock and the timer 1.
    CPU runs now at 8MHz, however timer 1 runs still at 8MHz / 8192,
    which is the same as 1MHz / 1024.
2026-05-06 Fix timer accuracy
    Originally the timer 1 tick is not 1us but actually 1ms / 1024.
    This change accurately pictures this in the duration ratios used for our
    data types. This also makes calculations in the seconds realm more
    efficient and precise, because the Timer::Hires_type >> 12 is now
    exactly one seconds.
    [main.cc]
2026-05-06 Use C++ progmem abstration in i2c code
    Thsi moves from explicit use of pgm_* functions in i2c code to use
    if Pgm<> and Pgm_ptr<> and Gen_ptr<>. This also reduces code size
    in the i2c code.
2026-05-06 I2C: add check for busy queue
2026-05-06 Add i2c data types for the master
2026-05-06 Add custom starter and finalizer for i2c commands
    This allows to handle the start and finish of i2c async cammd chains.
2026-05-06 Add code to display a countdown when running on timer
2026-05-06 Unify i2c commands
    C_send_bytes and C_send_bytes_ram are equivalent if we use Gen_ptr<> as
    pointer type. Additionally also cleanup the C_send_bytes_ram_len cmd.
    The neew code uses a helper class and a well defined data type
    I2c_master::Send_buffer_data and I2c_master::Send_buffer...
2026-05-06 Add button helper
    Add a cxx::Btn class on top of cxx::Debounce that supports double click
    and short click and long click as actions.
2026-05-06 main.cc: Use Task_list
    Make use of the task list template and reduce the clutter in the main
    loop of our program. This also removed a lot of ifdefs for i2c display
    support.
2026-05-06 Use Task_list init
    do no longer call individual init functions for taks, but use the
    Task_list::init function. This removes another i2c ifdef.
    [main.cc]
2026-05-06 Add _on state bit to Display and consolidate code
    Handle display state explicitely in Display::_on bit and consolidate all
    i2c and display related code to a single ifdef and the Display_task
    class. This also now switches the display off if ACC is on and no timer
    is running.
2026-05-06 Add some types ant time-type specific now()
    This change allows to programaticaly read the current time in different
    time formats depending on the required precision. And also allows to use
    the always under lock versions of the functions.
2026-05-06 Add Sleep_support class
    The sleep support class provides an API to setup MCU sleep and
    power-down modes, and to actually go to sleep.
2026-05-06 Optimize unused arguments
    Make sure unused arguments to update and wakeup functions of tasks are
    perfectly forwarded. This avoids costly dereferencing of potentially
    volatile state in those cases.
    [main.cc]
2026-05-06 Pass PINB as a pointer
    Pass a pointer to PINB as extra status to the task list. This way the
    loop will access the PINB directly whenever needed, instead of chaing
    the complete PINB value for the update functions.
2026-05-06 Display + i2c changes
    Improve i2c commands, add dynamic repeat byte command to i2c.
    Use a loop of prepared commands to show a clock on the display.
    Add other helper functions to blit pixmaps etc..
2026-05-06 Display changes
    Use vertical bitmaps and fonts. This allows for a simpler implementation
    of spacing in fonts. Switch the clock to a 7seg font.
2026-05-06 Display/I2C improvements
    Cleanups and restructuring: Make the display code robust against errors
    and try to re-initiate the display communication on erros.
    Use a newly added i2c command feature to enable control flow in the
    command interpreter.
    [i2c.h, main.cc]
